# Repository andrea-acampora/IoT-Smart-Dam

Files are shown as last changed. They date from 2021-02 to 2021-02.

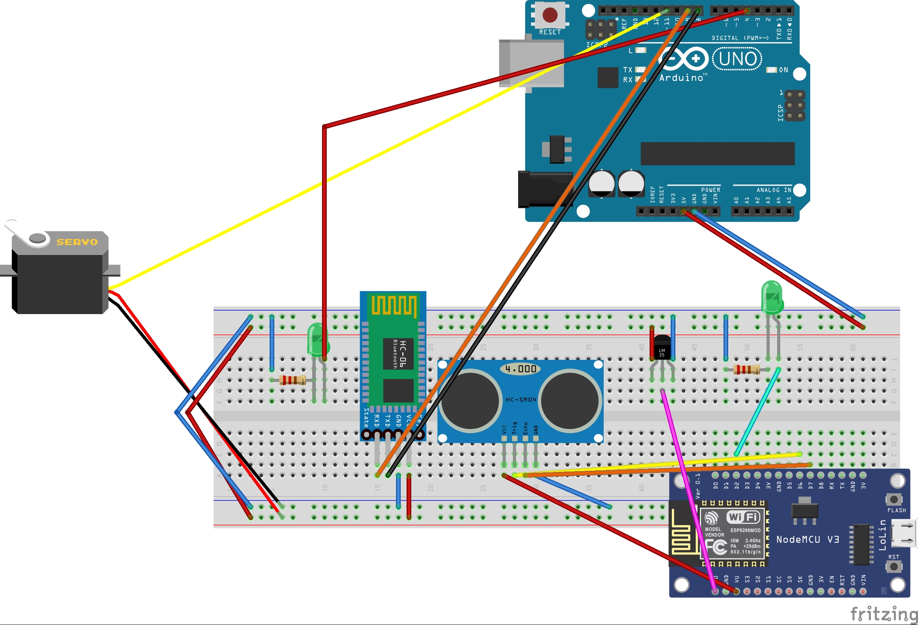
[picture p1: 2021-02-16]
doc/circuito_fritzing.jpg

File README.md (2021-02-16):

### 	Smart-Dam

 Repository  for *Sistemi Embedded & IoT* project of Università di Bologna.

The project aims to create a smart system with Arduino Uno and ESP8266 to perform water measurements and drive a smart-dam 		with WIFI, Bluetooth, Android comunications and a REST backend service.

All informations about the circuit and diagrams can be found at **/doc** folder.

The source code is available at **/src** folder.

**Usage:**

1. Upload the src/damRemoteHydrometer sketch on ESP8266 board.
2.  Upload the src/damController sketch on Arduino Uno board.
3.  Launch the src/damService as  Java application.
4. Upload and launch the src/damMobileApp on your device.
5. Open the src/damDashboard on your broswer.

**Authors:**

- Acampora Andrea
- Accursi Giacomo

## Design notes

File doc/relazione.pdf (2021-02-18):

# Relazione Assignment n.3

Autori: Acampora Andrea, Accursi Giacomo

# Remote Hydrometer

La rilevazione del livello dell'acqua è a carico del microcontrollore esp8266 che fa usa di un sonar. Il sottosistema è stato implementato con logica in termini di macchine a stati finiti sincrone.
I task individuati sono:
Tracking Task: si occupa di monitorare e aggiornare il livello dell'acqua utilizzando il sonar. Il task rimane attivo per tutta l'esecuzione del sistema.

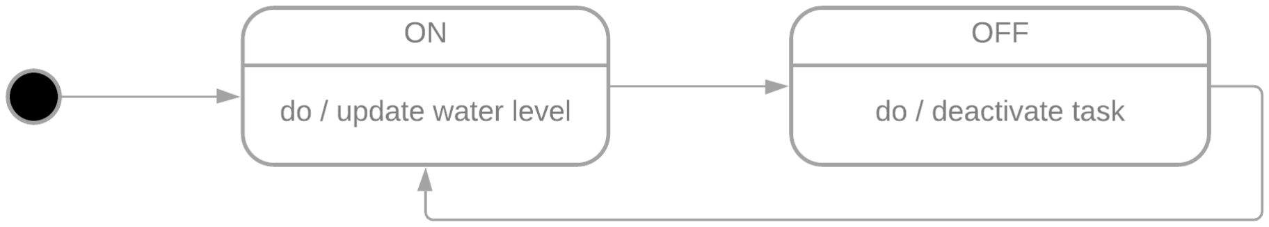
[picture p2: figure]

Sending Task: il task è attivo quando il sistema si trova in stato di PRE_ALLARME o ALLARME, mentre viene disattivato quando si trova in stato NORMALE. Il suo compito è quello di comunicare i dati (livello dell'acqua e stato del sistema), attraverso chiamate Post al Dam Service utilizzando il protocollo HTTP.

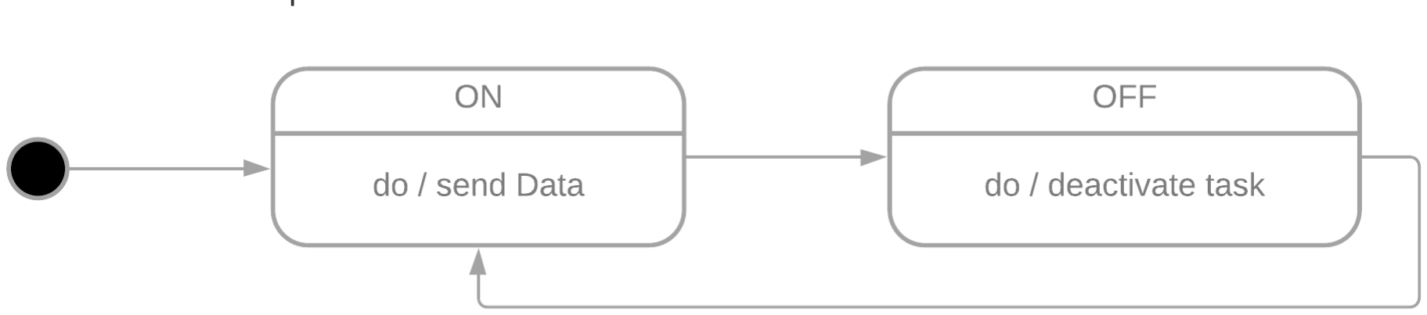
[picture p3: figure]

Blinking Task: viene attivato quando il sistema si trova in PRE_ALLARME. Ad ogni tick accende il LedAlarm se è spento e lo spegne se è acceso.

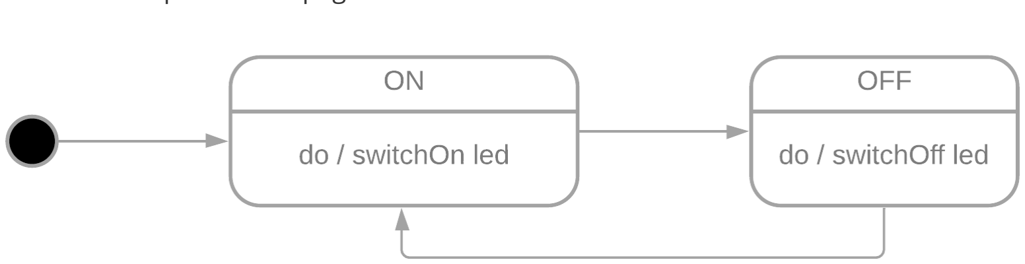
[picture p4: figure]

WaterLevelControllerTask: si accorge di cambiamenti nello stato del sistema e attiva o disattiva gli altri task di conseguenza.

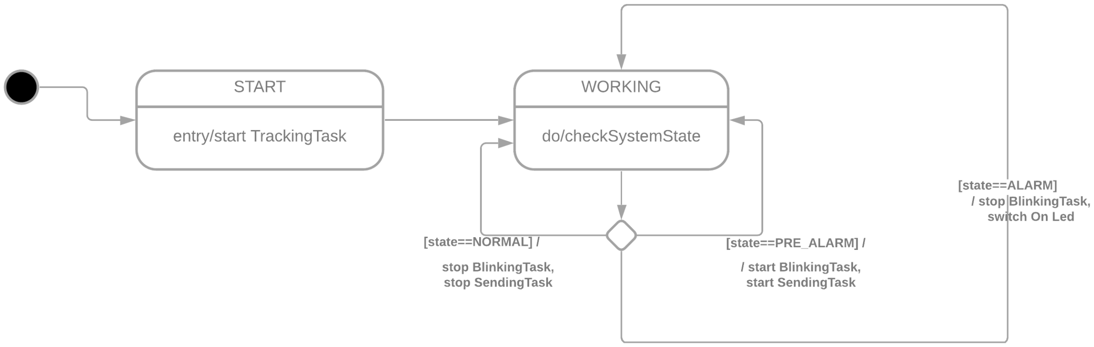
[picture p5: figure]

E' stato creato un oggetto WaterLevel, nel quale viene salvato il livello dell'acqua corrente. E' l'unico che conosce la logica con cui cambiare lo stato del sistema.
Componenti utilizzati:

Led verde
Sonar
Sensore di temperatura LM35 Microcontrollore Esp8266

# Dam Service

E' stato realizzato mediante un'applicazione Java che fa uso del toolkit Vert.x per gestire le chiamate HTTP provenienti da Remote Hydrometer, Dam Dashboard e Dam Mobile App.
Dam service è in grado di comunicare con gli altri sottosistemi grazie all'utilizzo dell'applicativo Ngrok che permette di raggiungere il server HTTP attraverso un indirizzo pubblico temporaneo. Il sistema è in grado di far fronte a diverse richieste HTTP mettendo a disposizione un'API per ognuna.

Il controller dell'applicazione è responsabile di mettere in comunicazione il model con il verticle e interagisce via seriale con il DamController per comunicare l'apertura della diga.
Il model contiene i metodi per accedere ai dati utili dell'applicazione e prende decisioni riguardo l'apertura della diga.
Per salvare lo storico delle rilevazioni è stato scelto di utilizzare un database. Per ognuna vengono salvati: livello dell'acqua, stato del sistema e momento della rilevazione.

La modalità (Manuale o Automatica) e il livello di apertura della diga non vengono salvati insieme alle rilevazioni perchè il loro cambiamento è asincrono rispetto a quest'ultime. E' il model ad occuparsi di queste informazioni, fornendole poi al controller su richiesta.

# Dam Controller

Per la realizzazione è stato deciso di utilizzare un approccio ad eventi utilizzando una macchina a stati finiti asincrona. E' stato scelto questo approccio poichè permette di evitare di controllare continuamente la presenza di nuove comunicazione da parte del Dam Service e della Dam Mobile App.

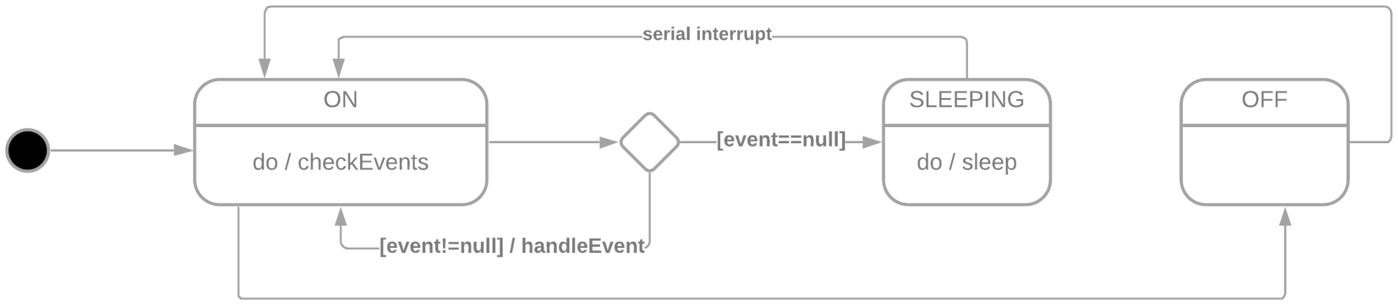
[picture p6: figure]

Ogni interruzione viene comunicata al proprio eventSource il quale ha il compito di valutarla per poi generare un evento il quale viene aggiunto nella coda della macchina a stati finiti.
Gli eventi individuati sono:
nuovo messaggio da parte del Dam Service sulla seriale
nuovo messaggio della Mobile App tramite bluetooth.
scadenza del timer utilizzato per il blink del led.

Le interruzioni sulla seriale, generate dall'arrivo dei caratteri, vengono notificate ad un event source che si occupa di leggerli e generare un evento in base al messaggio ricevuto.

Per la gestione del canale bluetooth è stata preferita la libreria AltSoftSerial rispetto a SoftwareSerial poichè quest'ultima causa problemi se usata insieme alla libreria EnableInterrupt. vedi qui (https://github.com/GreyGnome/EnableInterrupt/wiki/FAQ)
Per quanto riguarda la seriale hardware, la quale mette in comunicazione Dam Service e Dam controller, vengono abilitate le interruzioni sul pin RX di arduino, mentre per il canale bluetooth vengono abilitate le interruzioni sul pin 8, pin di ricezione usato da AltSoftSerial.
Il blink del Led viene effettuato attraverso l'utilizzo del timer0 che notifica la scadenza mediante interruzioni ad un event source per cambiare lo stato del led.
Sebbene venga sconsigliato l'utilizzo di timer0, poichè viene già utilizzato dalle funzioni millis(), delay() e micros() , era l'unico timer che avevamo a disposizione in quanto timer1 è utilizzato dalla libreria AltSoftSerial e timer2 dalla libreria ServoTimer2. Per evitare conflitti non abbiamo utilizzato le funzioni che utilizzano timer0.

Il sottosistema Dam Controller non è a conoscenza dello stato del sistema in quanto si tratta di una entità passiva che reagisce in base alle comunicazioni che arrivano. Il blink del led è attivo quando vengono ricevuti messaggi in modalità automatica.
Componenti utilizzati:

Microcontrollore Arduino Uno
Modulo bluetooth HC06
Servo Motore
Led verde

# Dam Mobile App

Sono stati utilizzati gli esempi relativi a richieste HTTP e connessione Bluetooth forniti dal prof. Croatti.
All'avvio dell'applicazione verrà mostrata la seguente schermata:

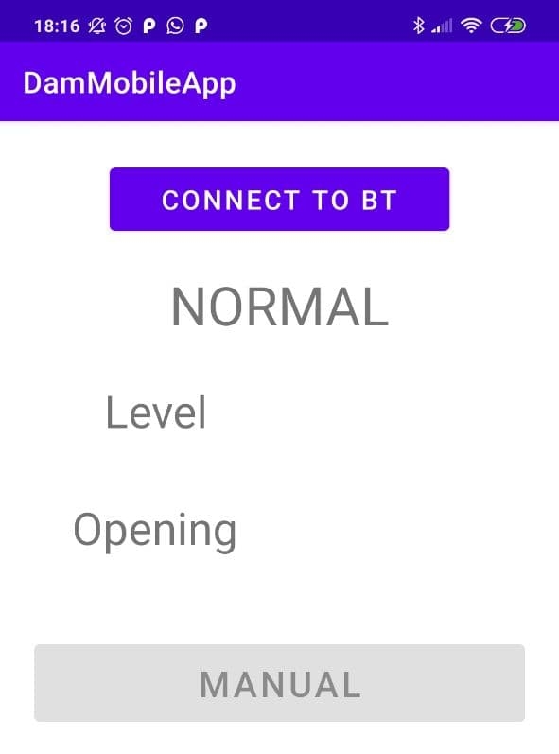
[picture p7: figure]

inizialmente il bottone per entrare in modalità manuale è disabilitato e verrà abilitato quando il sistema si troverà in stato di allarme. In qualunque momento è possibile connettersi ad Arduino tramite bluetooth utilizzando l'apposito bottone.

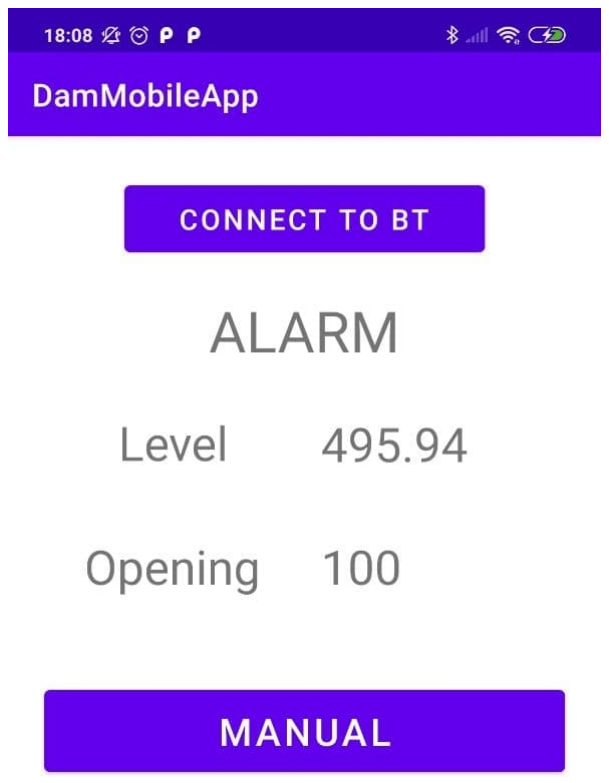
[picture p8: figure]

Una volta cliccato il bottone per entrare in modalità manuale, questo verrà segnalato al Dam Service mediante chiamata POST e apparirà la seguente schermata:

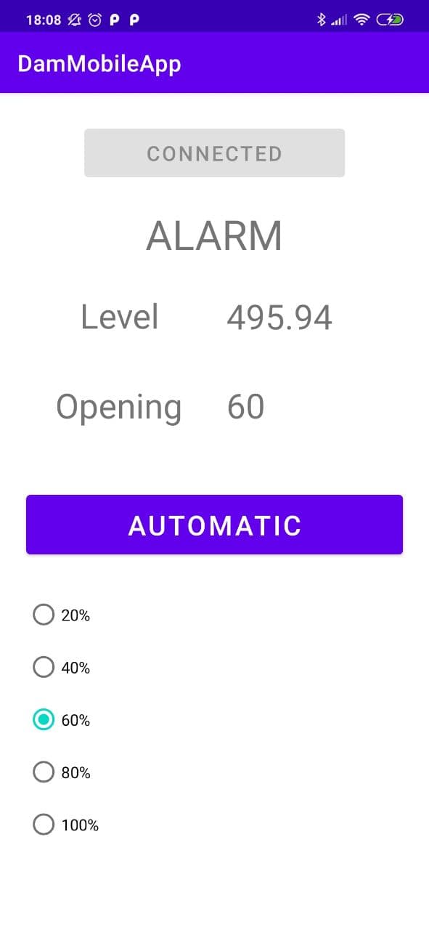
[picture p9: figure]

Cliccando su uno dei Radio-Button presenti verrà inviato un messaggio sul canale Bluetooth ad Arduino contenente il livello di apertura della diga scelto e verrà effettuata una chiamata POST al Dam Service per aggiornare i dati nel model dell'applicazione. Questo è necessario per fare in modo che anche la dashboard venga a conoscenza dell'attuale livello di apertura.

E' possibile tornare in modalità automatica cliccando nuovamente sul bottone . I radio-button a questo punto scompariranno, e l'app comunicherà al Dam Service la decisione.
Tutte le chiamate HTTP vengono effettuate facendo uso di un Async-Task il quale viene eseguito su un thread separato rispetto al MainThread. E' stato utilizzato l'Async-Task poichè le chiamate HTTP sono per loro natura asincrone. Una volta terminata la chiamata HTTP l'aggiornamento della view è a carico di un thread separato.
L'applicazione riporta in tempo reale i dati forniti forniti dal Dam Service con una frequenza di aggiornamento di 5 secondi.

# Dam Dashboard

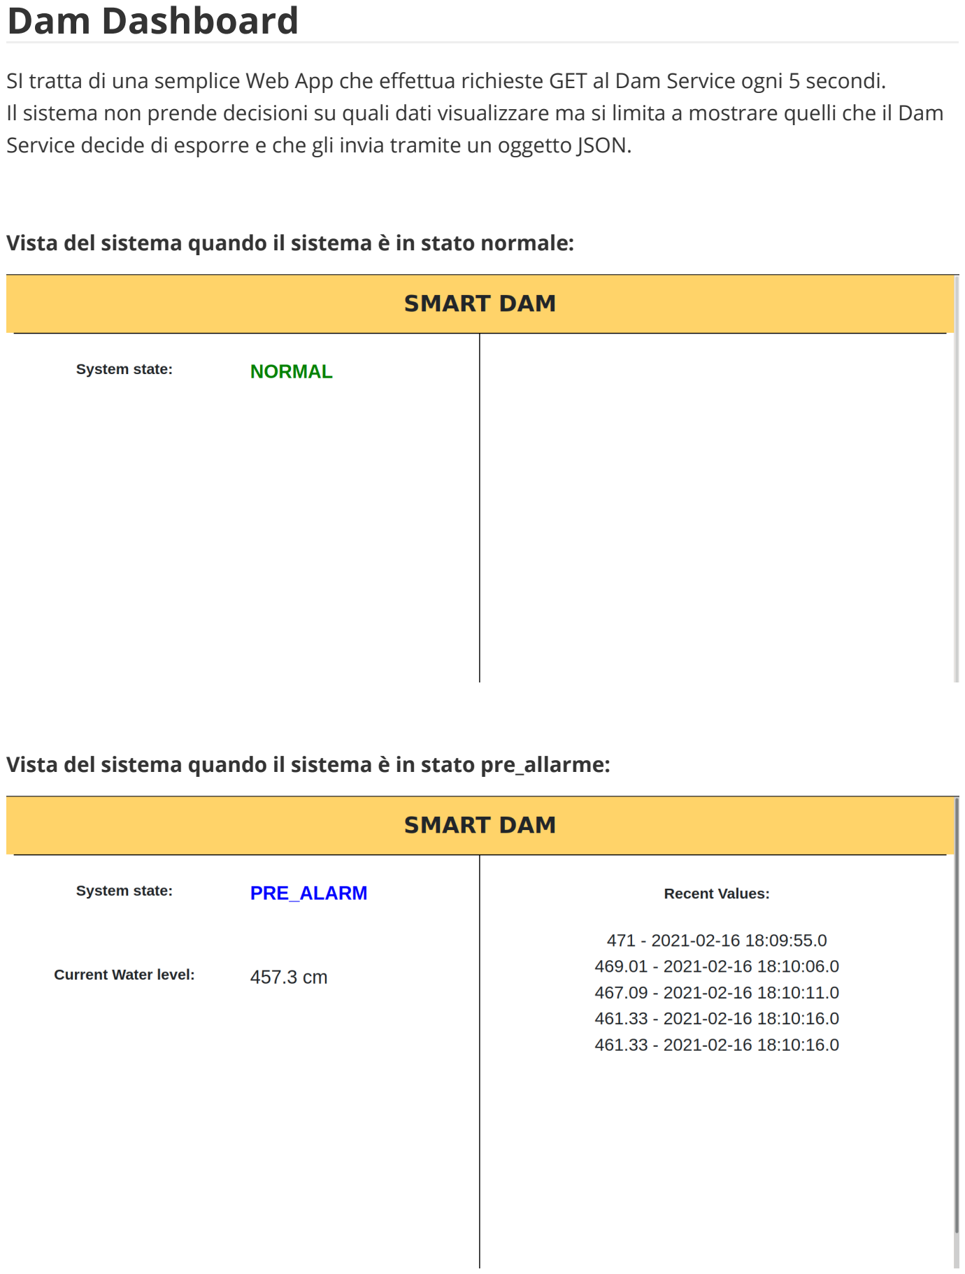
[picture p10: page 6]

SI tratta di una semplice Web App che effettua richieste GET al Dam Service ogni 5 secondi.
Il sistema non prende decisioni su quali dati visualizzare ma si limita a mostrare quelli che il Dam Service decide di esporre e che gli invia tramite un oggetto JSON.

Vista del sistema quando il sistema è in stato normale:

Vista del sistema quando il sistema è in stato pre_allarme:

Vista del sistema quando il sistema è in stato allarme:

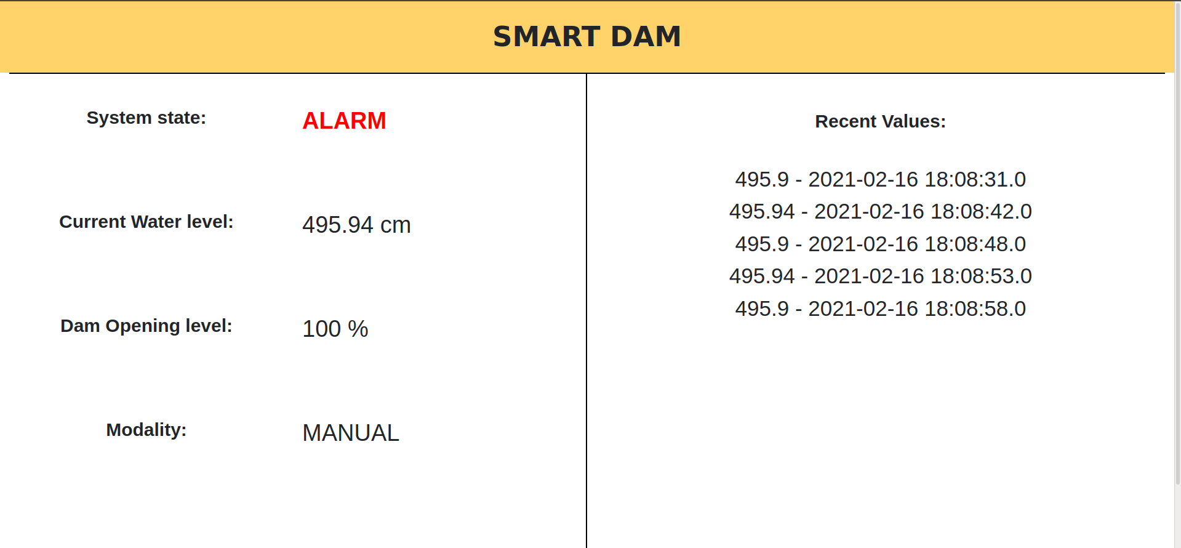
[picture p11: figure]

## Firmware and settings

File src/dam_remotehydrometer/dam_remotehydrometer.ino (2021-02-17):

#include <ESP8266WiFi.h>
#include "Scheduler.h"
#include "Task.h"
#include "SendingTask.h"
#include "TrackingTask.h"
#include "BlinkingTask.h"
#include "WaterLevel.h"
#include "WaterLevelControllerTask.h"
#include "Sonar.h"
#include "Light.h"
#include "Temp.h"
#include "globals.h"
#include "Led.h"
#include "DataSender.h"

Scheduler sched;

WaterLevelControllerTask* waterLevelControllerTask;
Task* blinkingTask;
Task* trackingTask;
Task* sendingTask;


Light* led_alarm;
Temp* temp;
Hydrometer* hydrometer;

WaterLevel* waterLevel;

char* ssidName = "TIM-CASA";
char* pwd = "tim3d208f6e03";
char* address = "http://97f343f83463.ngrok.io";


void setup() { 
  Serial.begin(115200);
  setupWiFi(ssidName,pwd);
  sched.init(100);
  createComponents();
  createTasks();
  initTasks();
  addTasks();                 
}

   
void loop() {
   sched.schedule();
}

void createComponents(){
  DataSender.init(address);
  led_alarm = new Led(PIN_LED_ALARM);
  temp = new Temp(PIN_TEMP);
  hydrometer = new Sonar(SONAR_TRIGGER_PIN, SONAR_ECHO_PIN,temp,GROUND_DISTANCE);
  waterLevel = new WaterLevel();
}

void createTasks(){
  blinkingTask = new BlinkingTask(led_alarm);
  trackingTask = new TrackingTask(hydrometer,waterLevel);
  sendingTask = new SendingTask(waterLevel);
  waterLevelControllerTask = new WaterLevelControllerTask(trackingTask, sendingTask, blinkingTask, waterLevel,led_alarm);
}

void initTasks(){
  blinkingTask -> init(500);
  trackingTask -> init(200);
  sendingTask -> init(FREQ_1);
  waterLevelControllerTask -> init(100);
  waterLevelControllerTask -> setActive(true);
}


void addTasks(){
  sched.addTask(waterLevelControllerTask);
  sched.addTask(sendingTask);
  sched.addTask(trackingTask);
  sched.addTask(blinkingTask);
}

void setupWiFi(char* ssidName,char* pwd){
    WiFi.begin(ssidName, pwd);
    Serial.print("Connecting...");
    while (WiFi.status() != WL_CONNECTED) {  
      delay(500);
      Serial.print(".");
     } 
  Serial.println("\n\n[+] Connected to: "+String(ssidName));
}

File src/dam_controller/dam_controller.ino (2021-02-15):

#include "Dam_Async_FSM.h"
#include "Light.h"
#include "Led.h"
#include "Dam.h"
#include "globals.h"
#include "SerialConsole.h"
#include "ConsoleBT.h"
#include "timerZero.h"
#include "TimerEventSource.h"

Light* led; 
SerialConsole* console;
ConsoleBT* consoleBT;
Dam* dam;
TimerEventSource* timerEventSource;

Dam_Async_FSM* dam_AsincFSM;

void setup() {
  Serial.begin(9600);
  dam = new Dam();
  led = new Led(PIN_LED_DAM);
  console = new SerialConsole();
  consoleBT = new ConsoleBT();
  timerEventSource = new TimerEventSource();
  dam_AsincFSM = new Dam_Async_FSM(led,dam,console,consoleBT,timerEventSource);
}

void loop() {
  dam_AsincFSM->checkEvents();
}

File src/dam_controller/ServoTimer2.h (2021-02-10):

/*
  ServoTimer2.h - Interrupt driven Servo library for Arduino using Timer2- Version 0.1
  Copyright (c) 2008 Michael Margolis.  All right reserved.

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
  You should have received a copy of the GNU Lesser General Public
  License along with this library; if not, write to the Free Software
  Foundation, Inc., 51 Franklin St, Fifth Floor, Boston, MA  02110-1301  USA
*/

// Updated for Arduino 1.x by Nick Bontrager 2013

/* 
  This library uses Timer2 to drive up to 8 servos using interrupts so no refresh activity is required from within the sketch. 
  The usage and method naming is similar to the Arduino software servo library http://www.arduino.cc/playground/ComponentLib/Servo
  except that pulse widths can be in microseconds or degrees.
  write() treats parameters of 180 or less as degrees, otherwise values are milliseconds.
 
  
  A servo is activated by creating an instance of the Servo class passing the desired pin to the attach() method.
  The servo is pulsed in the background to the value most recently written using the write() method

  Note that analogWrite of PWM on pins 3 and 11 is disabled when the first servo is attached

  The methods are:

   ServoTimer2 - Class for manipulating servo motors connected to Arduino pins.



   attach(pin )  - Attaches a servo motor to an i/o pin.

   attach(pin, min, max  ) - Attaches to a pin setting min and max values in microseconds

    default min is 544, max is 2400  

 

   write()     - Sets the servo pulse width in microseconds.



   read()      - Gets the last written servo pulse width in microseconds. 



   attached()  - Returns true if there is a servo attached. 



   detach()    - Stops an attached servos from pulsing its i/o pin. 
  


The library takes about 824 bytes of program memory and 32+(1*servos) bytes of SRAM. 

The pulse width timing is accurate to within 1%


 */

// ensure this library description is only included once
#ifndef ServoTimer2_h
#define ServoTimer2_h

#include <inttypes.h>
//typedef uint8_t boolean;
typedef uint8_t byte;

#define MIN_PULSE_WIDTH       750        // the shortest pulse sent to a servo  

#define MAX_PULSE_WIDTH      2250        // the longest pulse sent to a servo 

#define DEFAULT_PULSE_WIDTH  1500        // default pulse width when servo is attached

#define FRAME_SYNC_PERIOD   20000        // total frame duration in microseconds 

#define NBR_CHANNELS 8                   // the maximum number of channels, don't change this 

typedef struct  {

      uint8_t nbr        :5 ;  // a pin number from 0 to 31

      uint8_t isActive   :1 ;  // false if this channel not enabled, pin only pulsed if true 

   } ServoPin_t   ;  



typedef struct {

  ServoPin_t Pin;

  byte counter;

  byte remainder;

}  servo_t;

class ServoTimer2
{
  public:
  // constructor:
  ServoTimer2();

  uint8_t attach(int);     // attach the given pin to the next free channel, sets pinMode, returns channel number or 0 if failure
                           // the attached servo is pulsed with the current pulse width value, (see the write method) 
  uint8_t attach(int, int, int); // as above but also sets min and max values for writes. 
    void detach();
    void write(int);         // store the pulse width in microseconds (between MIN_PULSE_WIDTH and MAX_PULSE_WIDTH)for this channel
    int read();        // returns current pulse width in microseconds for this servo
  boolean attached();      // return true if this servo is attached 
 private:
   uint8_t chanIndex;      // index into the channel data for this servo

};


// the following ServoArrayT2 class is not implemented in the first version of this library
class ServoArrayT2
{
  public:
  // constructor:
  ServoArrayT2();

  uint8_t attach(int);     // attach the given pin to the next free channel, sets pinMode, returns channel number or 0 if failure
                           // channels are assigned consecutively starting from 1
                           // the attached servo is pulsed with the current pulse width value, (see the write method) 
    void detach(int);        // detach the servo on the given channel
  void write(int,int);     // store the pulse width in microseconds (between MIN_PULSE_WIDTH and MAX_PULSE_WIDTH)for the given channel
    int read(int);       // returns current pulse width in microseconds for the given channel
  boolean attached(int);   // return true if the servo on the given channel is attached 
 private:
   uint8_t chanIndex;      // index into the channel data for this servo

};

#endif

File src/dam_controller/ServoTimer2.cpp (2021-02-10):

extern "C" {
  // AVR LibC Includes
  #include <inttypes.h>
  #include <avr/interrupt.h>
  // #include "WConstants.h"
}
#include <Arduino.h>
#include "ServoTimer2.h"
static void initISR();   
static void writeChan(uint8_t chan, int pulsewidth);

#define FRAME_SYNC_INDEX   0     // frame sync delay is the first entry in the channel array
#define FRAME_SYNC_PERIOD  20000     // total frame duration in microseconds 
#define FRAME_SYNC_DELAY   ((FRAME_SYNC_PERIOD - ( NBR_CHANNELS * DEFAULT_PULSE_WIDTH))/ 128) // number of iterations of the ISR to get the desired frame rate
#define DELAY_ADJUST   8     // number of microseconds of calculation overhead to be subtracted from pulse timings   

static servo_t servos[NBR_CHANNELS+1];    // static array holding servo data for all channels

static volatile uint8_t Channel;   // counter holding the channel being pulsed
static volatile uint8_t ISRCount;  // iteration counter used in the interrupt routines;
uint8_t ChannelCount = 0;     // counter holding the number of attached channels
static boolean isStarted = false;  // flag to indicate if the ISR has been initialised

ISR (TIMER2_OVF_vect)
{ 
  ++ISRCount; // increment the overlflow counter
  if (ISRCount ==  servos[Channel].counter ) // are we on the final iteration for this channel
  {
  TCNT2 =  servos[Channel].remainder;   // yes, set count for overflow after remainder ticks
  }  
  else if(ISRCount >  servos[Channel].counter)  
  {
  // we have finished timing the channel so pulse it low and move on
  if(servos[Channel].Pin.isActive == true)       // check if activated
      digitalWrite( servos[Channel].Pin.nbr,LOW); // pulse this channel low if active   

    Channel++;    // increment to the next channel
  ISRCount = 0; // reset the isr iteration counter 
  TCNT2 = 0;    // reset the clock counter register
  if( (Channel != FRAME_SYNC_INDEX) && (Channel <= NBR_CHANNELS) ){      // check if we need to pulse this channel    
      if(servos[Channel].Pin.isActive == true)     // check if activated
     digitalWrite( servos[Channel].Pin.nbr,HIGH); // its an active channel so pulse it high   
  }
  else if(Channel > NBR_CHANNELS){ 
     Channel = 0; // all done so start over      
  } 
   }  
}

ServoTimer2::ServoTimer2()
{
   if( ChannelCount < NBR_CHANNELS)  
  this->chanIndex = ++ChannelCount;  // assign a channel number to this instance
   else
  this->chanIndex = 0;  // todo // too many channels, assigning 0 inhibits this instance from functioning 
}

uint8_t ServoTimer2::attach(int pin)
{
  if( isStarted == false)
   initISR();    
  if(this->chanIndex > 0)  
  {
   //debug("attaching chan = ", chanIndex);
   pinMode( pin, OUTPUT) ;  // set servo pin to output
   servos[this->chanIndex].Pin.nbr = pin;  
   servos[this->chanIndex].Pin.isActive = true;  
  } 
  return this->chanIndex ;
}

void ServoTimer2::detach()  
{
    servos[this->chanIndex].Pin.isActive = false;  
}

void ServoTimer2::write(int pulsewidth)
{ 
   writeChan(this->chanIndex, pulsewidth); // call the static function to store the data for this servo     
}

int ServoTimer2::read()
{
  unsigned int pulsewidth;
   if( this->chanIndex > 0)
  pulsewidth =  servos[this->chanIndex].counter * 128 + ((255 - servos[this->chanIndex].remainder) / 2) + DELAY_ADJUST ;
   else 
   pulsewidth  = 0;
   return pulsewidth;   
}
 
boolean ServoTimer2::attached()
{
    return servos[this->chanIndex].Pin.isActive ;
}

static void writeChan(uint8_t chan, int pulsewidth)
{
   // calculate and store the values for the given channel
   if( (chan > 0) && (chan <= NBR_CHANNELS) )   // ensure channel is valid
   { 
  if( pulsewidth < MIN_PULSE_WIDTH )        // ensure pulse width is valid
      pulsewidth = MIN_PULSE_WIDTH;
  else if( pulsewidth > MAX_PULSE_WIDTH )
      pulsewidth = MAX_PULSE_WIDTH;  
  
    pulsewidth -=DELAY_ADJUST;       // subtract the time it takes to process the start and end pulses (mostly from digitalWrite) 
  servos[chan].counter = pulsewidth / 128;  
  servos[chan].remainder = 255 - (2 * (pulsewidth - ( servos[chan].counter * 128)));  // the number of 0.5us ticks for timer overflow    
   }
}

static void initISR()
{   
  for(uint8_t i=1; i <= NBR_CHANNELS; i++) {  // channels start from 1    
     writeChan(i, DEFAULT_PULSE_WIDTH);  // store default values      
  }
  servos[FRAME_SYNC_INDEX].counter = FRAME_SYNC_DELAY;   // store the frame sync period  

  Channel = 0;  // clear the channel index  
  ISRCount = 0;  // clear the value of the ISR counter;
  
  /* setup for timer 2 */
  TIMSK2 = 0;  // disable interrupts 
  TCCR2A = 0;  // normal counting mode 
  TCCR2B = _BV(CS21); // set prescaler of 8 
  TCNT2 = 0;     // clear the timer2 count 
  TIFR2 = _BV(TOV2);  // clear pending interrupts; 
  TIMSK2 =  _BV(TOIE2) ; // enable the overflow interrupt   
    
  isStarted = true;  // flag to indicate this initialisation code has been executed
} 

 

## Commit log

2021-02-11 prova libreria per timer0
2021-02-15 added separate thread to update ui
2021-02-15 added new thread for mobile App
2021-02-16 Added documentation
    [circuit.fzz]
2021-02-17 Added power save state
2021-02-17 Removed unused led for testing power save mode
